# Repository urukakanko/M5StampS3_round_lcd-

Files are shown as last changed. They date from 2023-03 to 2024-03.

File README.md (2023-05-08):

# M5StampS3ラウンド液晶モジュール

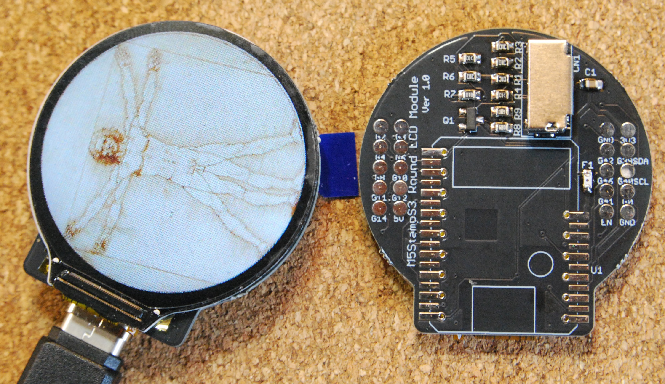
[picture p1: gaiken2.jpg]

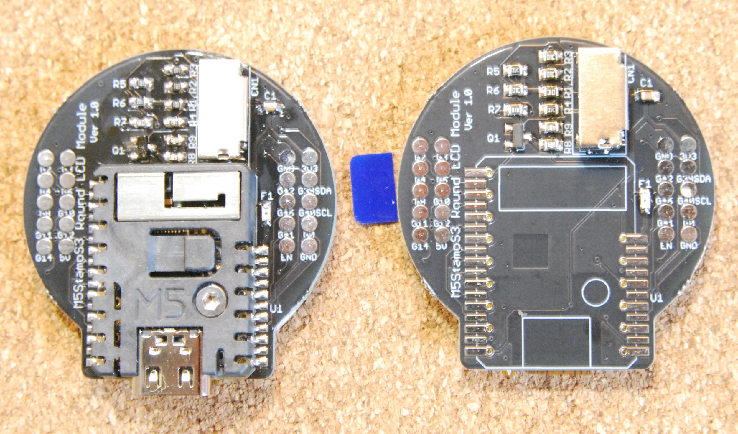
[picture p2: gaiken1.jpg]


写真左：M5StampS3実装済　　　　写真右：M5StampS3未実装

M5StampS3を使用して1.28インチ240ｘ240ドットの円形液晶を駆動する基板モジュールです。

円形液晶の裏にM5StampS3を配置することで、とても小さくスリムな形状になりました。

円形液晶にはGC9A01というコントローラーが使用されていますが、対応したグラフィックライブラリが数種類公開されています。

本モジュールは「グラフィックライブラリの使い方を理解して液晶モジュールを駆動出来る人」をターゲットにしております。

# 2023年5月5日までにM5StampS3実装品を購入された方へのお詫び

裏面のMacAddressがプリントされたラベルと実際のMacAddressが異なっている可能性があります。

MacAddress情報が必要な場合は以下サンプルソースで画面表示する様にしましたのでこちらで確認をお願いします。

大変ご迷惑をお掛けしてしまい申し訳ございません。

https://github.com/urukakanko/M5StampS3_round_lcd-/tree/main/M5stampS3_ClockSample

# <span style="color: red;">注意！！（必ずお読み下さい）</span>

本品は基本的な電子回路の仕組みを理解した方を対象とした、電子部品がむき出しの半完成キットです。
電子部品は電源電圧や極性を間違えたり、部品を破損させたり部品端子をショートさせた場合、発熱・発煙・発火に至る場合もあります。
間違った使い方をすると危険である事を理解された方のみご使用ください。
趣味の電子工作向けに製作しておりますので、製品への組込みや日常生活へ組込んでのご使用はお控え下さい。

# 形状および回路図

以下に外形イメージを示します

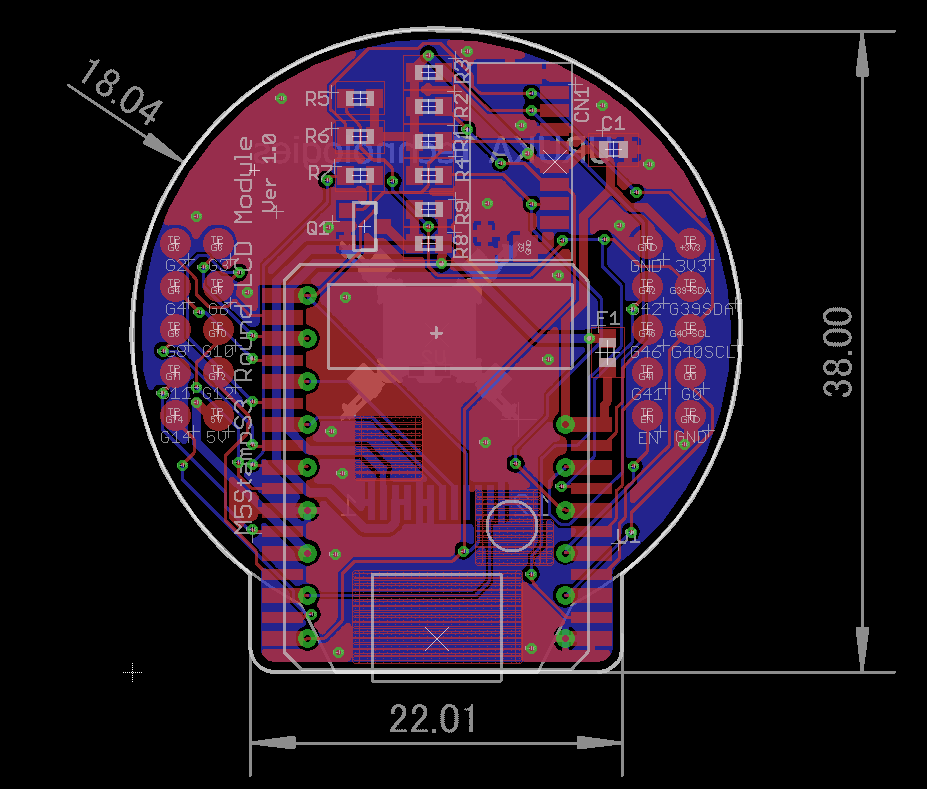
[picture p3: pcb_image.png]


以下に回路図を示します　現在最新は基板Ver1.0です

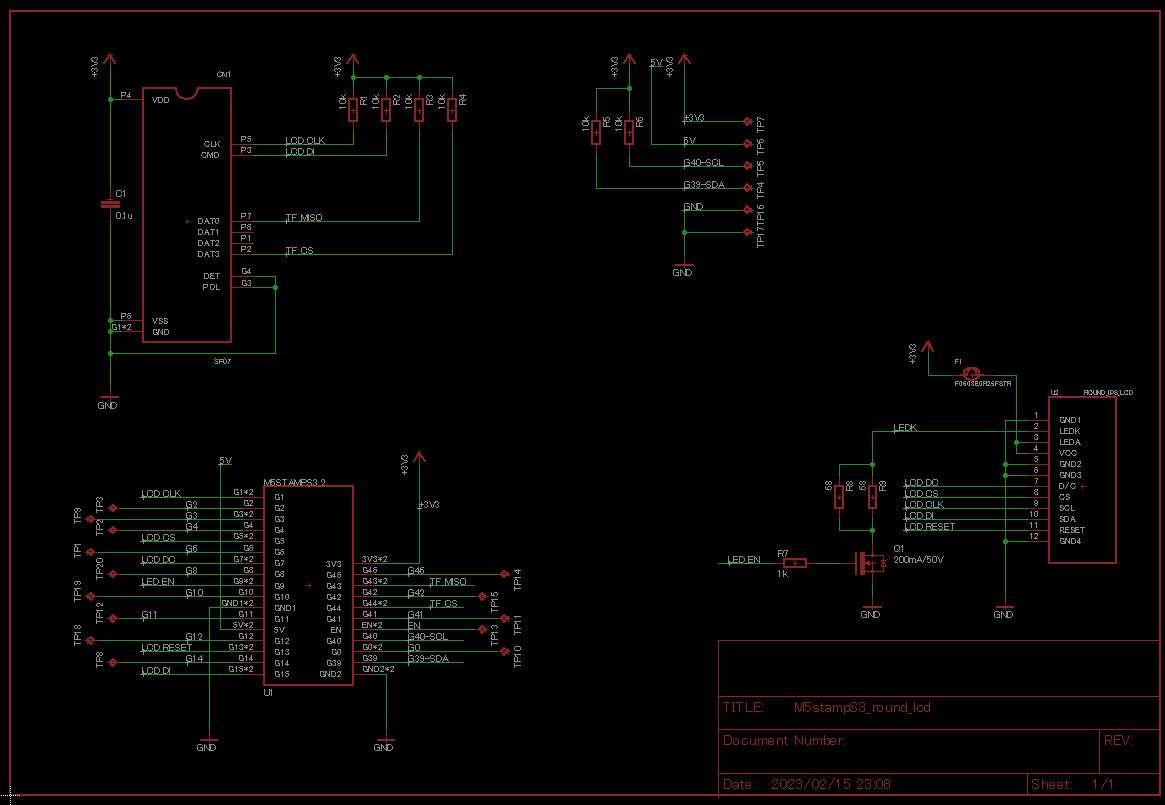
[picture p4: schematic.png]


試作版のVer0.1の図面は以下に保存しています

https://github.com/urukakanko/M5StampS3_round_lcd-/tree/main/ver0.1

# ピンアサイン

M5Stamp とLCDの制御信号とのピン接続は以下となります。

- SCLK:G1

- DATA-IN:G15

- DC:G7

- CS:G5

- RST:G13

- バックライト:G9　バックライトLEDのPIN設定は必ず行ってください。ハイインピーダンスとなった場合バックライトが不安定になります。

TFカードスロットのPIN接続は以下となります。（SCLKおよびMOSIは液晶と共通です）

- TF-MISO:G43
- TF-CS:44

また、以下の未使用PINはパットで引き出せるようにしました。I2C接続を想定しG39とG40にはプルアップをしています。

- G2,G3,G4,G6,G8,G10,G11,G12,G14,G39,G0,G40,EN,G41,G42,G46

注意：リード線をハンダ付けするパットとして使用します　コネクタやピンヘッダは挿せません。

# 使用するツールやライブラリ

M5StampS3の情報については、以下サイトを参考下さい。

https://docs.m5stack.com/en/core/StampS3

グラフィックライブラリについてはlovyanさまのLovyanGFXにて動作確認をしています。

https://github.com/lovyan03/LovyanGFX

他、GC9A01に対応したライブラリが使用可能と考えています。

# サンプルプログラム

LovyanGFXのClockSampleです

https://github.com/urukakanko/M5StampS3_round_lcd-/tree/main/M5stampS3_ClockSample

# LCD表示動画

BMPデータを液晶に表示しています

[https://youtu.be/gN_2BcIaoQU](https://youtu.be/WFxbUNVwUNw)

未実装版のチェックをしている動画です

https://youtu.be/jMZeYKtBkwM

# そーたメイ氏の「つくるっち」に対応して頂きました

以下はアニメーションデモです

https://sohta02.sakura.ne.jp/tukurutch/#000000531

# 使用例

準備中

# スイッチサイエンスマーケットプレイスで販売しています

M5StampS3実装品

https://www.switch-science.com/products/8971

M5StampS3未実装品

https://www.switch-science.com/products/8851

# 製作者

ウルカテクノロジー
Hiroyuki Sunagawa

https://www.facebook.com/URUKA-Technologies-105478404379918

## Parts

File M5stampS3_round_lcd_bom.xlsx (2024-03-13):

Column1 | Column2 | Column3 | Column4 | Column5
Part | Value | Device | Package | Description
C1 | 0.1u | C-EUC0603 | C0603 | CAPACITOR, European symbol
CN1 | 8pin | HYC80-TF08-375 |  | mini TF card socket
F1 | 250mA | FUSE0603 | C0603 | Can be replaced with 0 ohm resistor
Q1 | BSS138 | MOSFET-NCHANNELBSS138 | SOT23-3
R1 | 10k | R-EU_R0603 | R0603 | RESISTOR
R2 | 10k | R-EU_R0603 | R0603 | RESISTOR
R3 | 10k | R-EU_R0603 | R0603 | RESISTOR
R4 | 10k | R-EU_R0603 | R0603 | RESISTOR
R5 | 10k | R-EU_R0603 | R0603 | RESISTOR
R6 | 10k | R-EU_R0603 | R0603 | RESISTOR
R7 | 1k | R-EU_R0603 | R0603 | RESISTOR
R8 | 68 | R-EU_R0603 | R0603 | RESISTOR
R9 | 68 | R-EU_R0603 | R0603 | RESISTOR
U1 | M5STAMPS3 | M5STAMPS3 | M5STAMPS3
U2 | ROUND_IPS_LCD | ROUND_IPS_LCD | ROUND_IPS_LCD

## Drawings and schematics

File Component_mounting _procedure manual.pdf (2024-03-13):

# Component mounting procedure manual

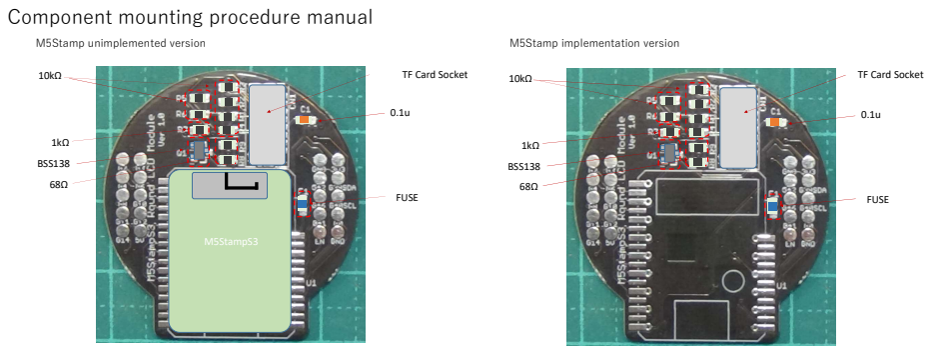
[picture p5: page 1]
M5Stamp unimplemented version; M5Stamp implementation version; M5Stamp実装品; M5StampS3; FUSE; BSS138; 1kΩ BSS138; TF Card Socket

# Round LCD implementation

Front side | Back side

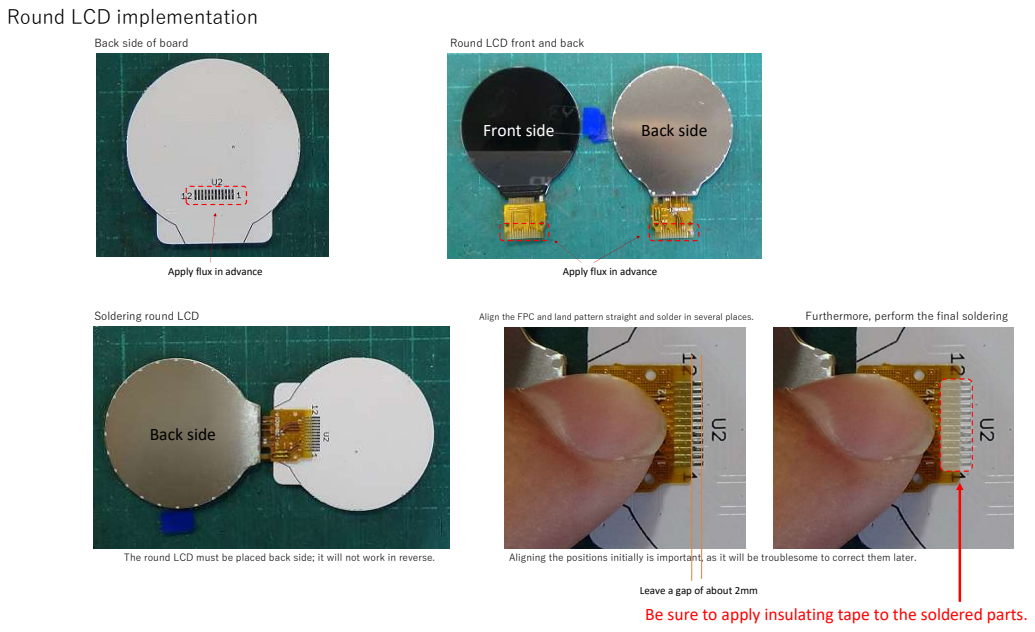
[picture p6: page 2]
Back side of board; Round LCD front and back; Soldering round LCD; Align the FPC and land pattern straight and solder in several places.; Furthermore, perform the final soldering; The round LCD must be placed back side; it will not work in reverse.; Aligning the positions initially is important, as it will be troublesome to correct them later.; Apply flux in advance; Back side

Leave a gap of about 2mm
Be sure to apply insulating tape to the soldered parts.

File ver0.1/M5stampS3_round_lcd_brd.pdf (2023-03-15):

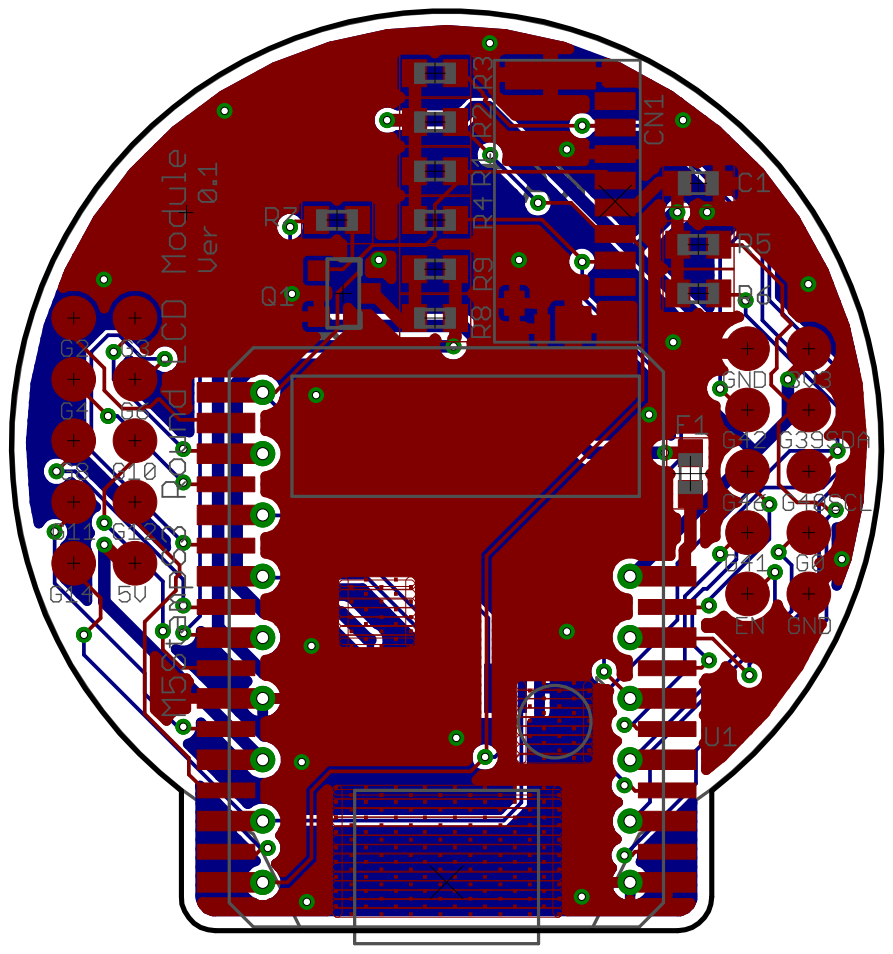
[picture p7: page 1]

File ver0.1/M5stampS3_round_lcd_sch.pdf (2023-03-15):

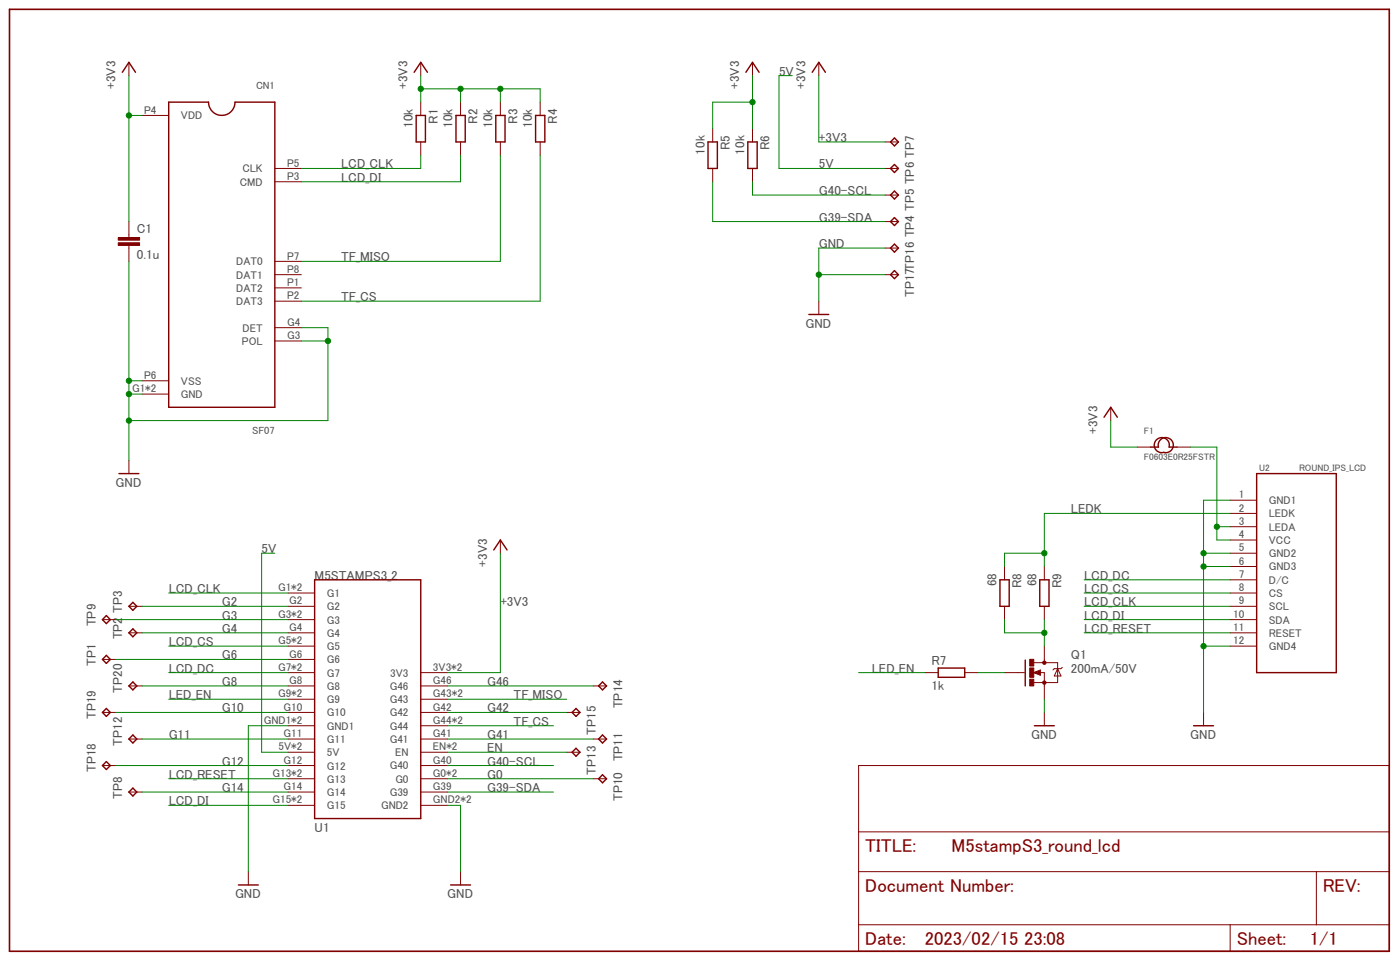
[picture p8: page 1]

Document Number: | REV:

Date: 2023/02/15 23:08 | Sheet: 1/1

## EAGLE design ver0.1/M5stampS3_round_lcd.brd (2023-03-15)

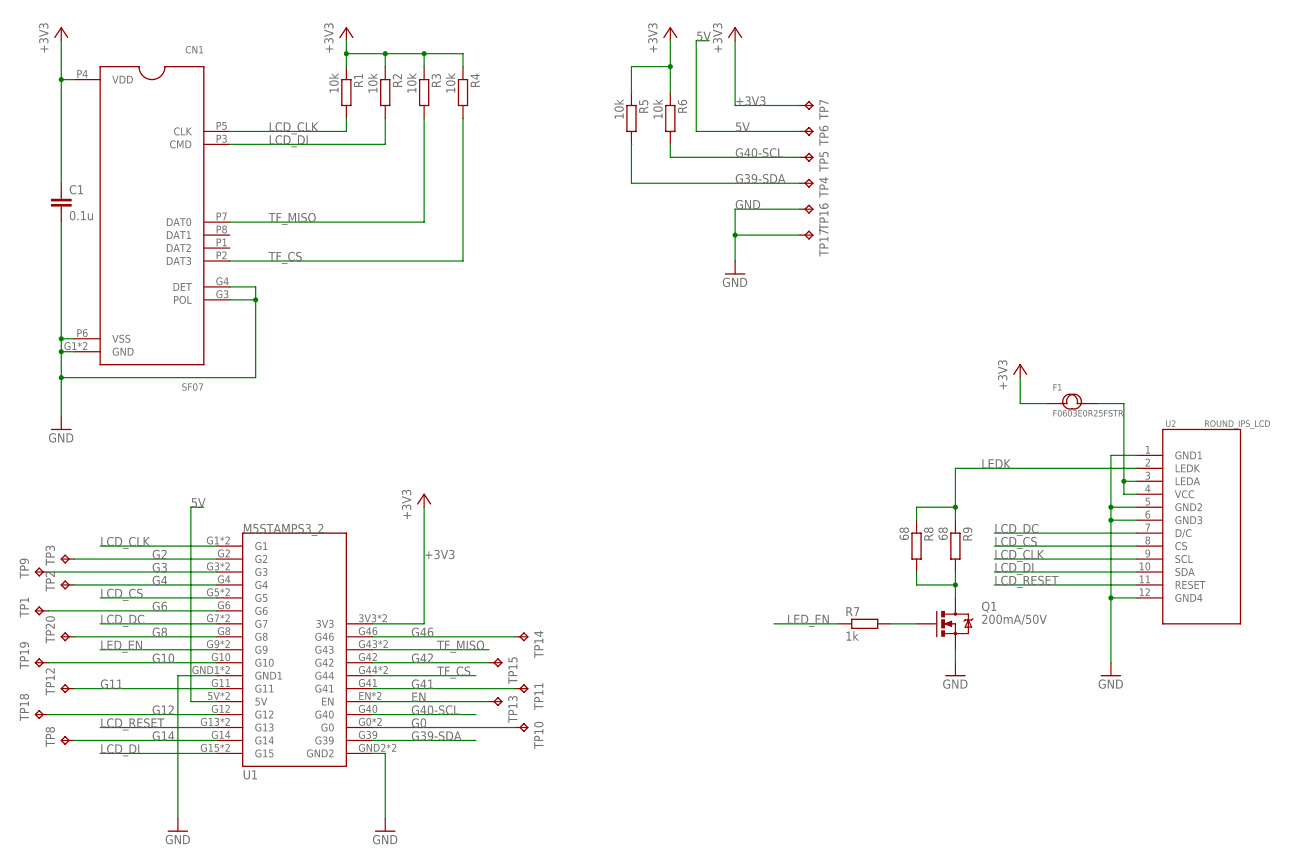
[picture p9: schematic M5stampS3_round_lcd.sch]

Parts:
C1: 0.1u; C0603
CN1: SF07; POS-8
F1: F0603E0R25FSTR; C0603
Q1: 200mA/50V; SOT23-3
R1, R2, R3, R4, R5, R6: 10k; R0603
R7: 1k; R0603
R8, R9: 68; R0603
TP1, TP2, TP3, TP4, TP5, TP6, TP7, TP8, TP9, TP10, TP11, TP12, TP13, TP14, TP15, TP16, TP17, TP18, TP19, TP20: TPTP18R; TP18R
U1: M5STAMPS3_2
U2: ROUND_IPS_LCD

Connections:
5V: TP6.TP, U1.5V, U1.5V_ (5V)
+3V3: C1.1, CN1.P4 (VDD), F1.1, R1.1, R2.1, R3.1, R4.1, R5.1, R6.1, TP7.TP, U1.3V3, U1.3V3_ (3V3)
EN: TP13.TP, U1.EN, U1.EN_ (EN)
G0: TP10.TP, U1.G0, U1.G0_ (G0)
G2: TP3.TP, U1.G2
G3: TP9.TP, U1.G3, U1.G3_ (G3)
G4: TP2.TP, U1.G4
G6: TP1.TP, U1.G6
G8: TP20.TP, U1.G8
G10: TP19.TP, U1.G10
G11: TP12.TP, U1.G11
G12: TP18.TP, U1.G12
G14: TP8.TP, U1.G14
G39-SDA: R5.2, TP4.TP, U1.G39
G40-SCL: R6.2, TP5.TP, U1.G40
G41: TP11.TP, U1.G41
G42: TP15.TP, U1.G42
G46: TP14.TP, U1.G46
GND: C1.2, CN1.G1 (GND), CN1.G2 (GND), CN1.G3 (POL), CN1.G4 (DET), CN1.P6 (VSS), Q1.2 (S), TP16.TP, TP17.TP, U1.GND1, U1.GND1_ (GND1), U1.GND2, U1.GND2_ (GND2), U2.1 (GND1), U2.5 (GND2), U2.6 (GND3), U2.12 (GND4)
LCD_CLK: CN1.P5 (CLK), R1.2, U1.G1, U1.G1_ (G1), U2.9 (SCL)
LCD_CS: U1.G5, U1.G5_ (G5), U2.8 (CS)
LCD_DC: U1.G7, U1.G7_ (G7), U2.7 (D/C)
LCD_DI: CN1.P3 (CMD), R2.2, U1.G15, U1.G15_ (G15), U2.10 (SDA)
LCD_RESET: U1.G13, U1.G13_ (G13), U2.11 (RESET)
LEDK: R8.1, R9.1, U2.2 (LEDK)
LED_EN: R7.1, U1.G9, U1.G9_ (G9)
unnamed: Q1.3 (D), R8.2, R9.2
unnamed: Q1.1 (G), R7.2
unnamed: F1.2, U2.3 (LEDA), U2.4 (VCC)
TF_CS: CN1.P2 (DAT3), R4.2, U1.G44, U1.G44_ (G44)
TF_MISO: CN1.P7 (DAT0), R3.2, U1.G43, U1.G43_ (G43)

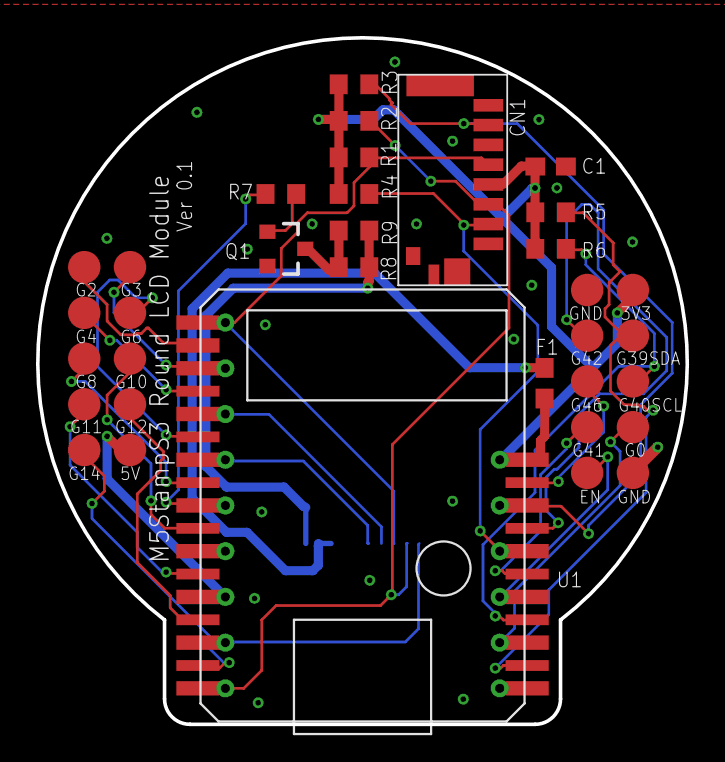
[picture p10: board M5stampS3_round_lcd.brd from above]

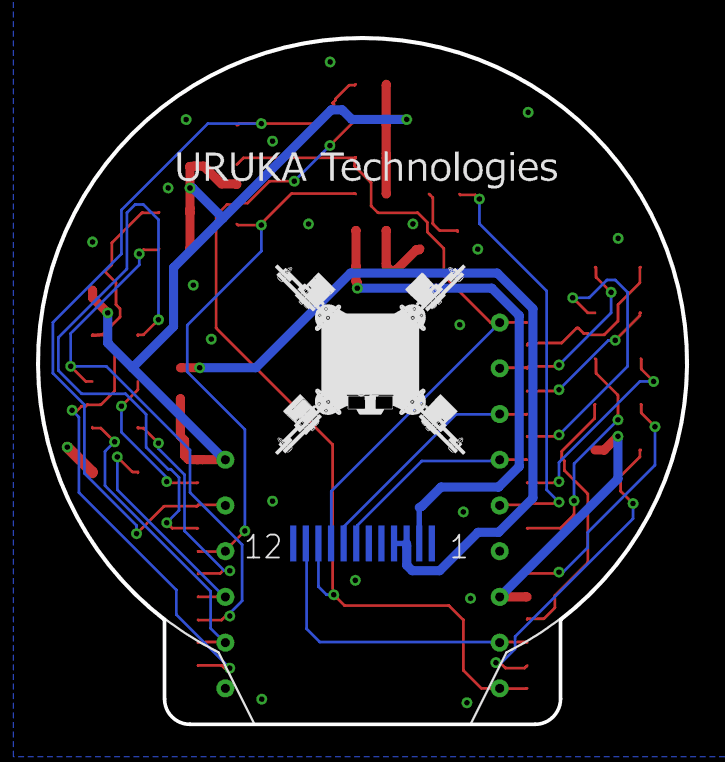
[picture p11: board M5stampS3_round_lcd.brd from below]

Board: 2 copper layers, 36.1 x 38.1 mm, 37 parts (2 on the bottom side), 31 nets.

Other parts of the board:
U$1: QC02
U$2: URUKA

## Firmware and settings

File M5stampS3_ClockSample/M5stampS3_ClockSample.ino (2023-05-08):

#define LGFX_USE_V1
#include <LovyanGFX.hpp>

class LGFX_ESP32_SPI_GC9A01 : public lgfx::LGFX_Device
{
lgfx::Panel_GC9A01      _panel_instance;
lgfx::Bus_SPI       _bus_instance;   // SPIバスのインスタンス
lgfx::Light_PWM     _light_instance;
public:
  LGFX_ESP32_SPI_GC9A01(void)
  {
    { // バス制御の設定を行います。
      auto cfg = _bus_instance.config();    // バス設定用の構造体を取得します。

// SPIバスの設定
      cfg.spi_host = SPI2_HOST;     // 使用するSPIを選択  ESP32-S2,C3 : SPI2_HOST or SPI3_HOST / ESP32 : VSPI_HOST or HSPI_HOST
      // ※ ESP-IDFバージョンアップに伴い、VSPI_HOST , HSPI_HOSTの記述は非推奨になるため、エラーが出る場合は代わりにSPI2_HOST , SPI3_HOSTを使用してください。
      cfg.spi_mode = 0;             // SPI通信モードを設定 (0 ~ 3)
      cfg.freq_write = 40000000;    // 送信時のSPIクロック (最大80MHz, 80MHzを整数で割った値に丸められます)
      cfg.freq_read  = 16000000;    // 受信時のSPIクロック
      cfg.spi_3wire  = true;        // 受信をMOSIピンで行う場合はtrueを設定
      cfg.use_lock   = true;        // トランザクションロックを使用する場合はtrueを設定
      cfg.dma_channel = SPI_DMA_CH_AUTO; // 使用するDMAチャンネルを設定 (0=DMA不使用 / 1=1ch / 2=ch / SPI_DMA_CH_AUTO=自動設定)
      // ※ ESP-IDFバージョンアップに伴い、DMAチャンネルはSPI_DMA_CH_AUTO(自動設定)が推奨になりました。1ch,2chの指定は非推奨になります。
      cfg.pin_sclk = 1;            // SPIのSCLKピン番号を設定
      cfg.pin_mosi = 15;            // SPIのMOSIピン番号を設定
      cfg.pin_miso = 43;            // SPIのMISOピン番号を設定 (-1 = disable)
      cfg.pin_dc   = 7;            // SPIのD/Cピン番号を設定  (-1 = disable)
     // SDカードと共通のSPIバスを使う場合、MISOは省略せず必ず設定してください。
      _bus_instance.config(cfg);    // 設定値をバスに反映します。
      _panel_instance.setBus(&_bus_instance);      // バスをパネルにセットします。
    }

    { // 表示パネル制御の設定を行います。
      auto cfg = _panel_instance.config();    // 表示パネル設定用の構造体を取得します。
      cfg.pin_cs           =    5;  // CSが接続されているピン番号   (-1 = disable)
      cfg.pin_rst          =    13;  // RSTが接続されているピン番号  (-1 = disable)
      cfg.pin_busy         =    -1;  // BUSYが接続されているピン番号 (-1 = disable)
      // ※ 以下の設定値はパネル毎に一般的な初期値が設定されていますので、不明な項目はコメントアウトして試してみてください。
      cfg.memory_width     =   240;  // ドライバICがサポートしている最大の幅
      cfg.memory_height    =   240;  // ドライバICがサポートしている最大の高さ
      cfg.panel_width      =   240;  // 実際に表示可能な幅
      cfg.panel_height     =   240;  // 実際に表示可能な高さ
      cfg.offset_x         =     0;  // パネルのX方向オフセット量
      cfg.offset_y         =     0;  // パネルのY方向オフセット量
      cfg.offset_rotation  =     0;  // 回転方向の値のオフセット 0~7 (4~7は上下反転)
      cfg.dummy_read_pixel =     8;  // ピクセル読出し前のダミーリードのビット数
      cfg.dummy_read_bits  =     1;  // ピクセル以外のデータ読出し前のダミーリードのビット数
      cfg.readable         =  true;  // データ読出しが可能な場合 trueに設定
      cfg.invert           =  true;  // パネルの明暗が反転してしまう場合 trueに設定
      cfg.rgb_order        = false;  // パネルの赤と青が入れ替わってしまう場合 trueに設定
      cfg.dlen_16bit       = false;  // データ長を16bit単位で送信するパネルの場合 trueに設定
      cfg.bus_shared       =  true;  // SDカードとバスを共有している場合 trueに設定(drawJpgFile等でバス制御を行います)

      _panel_instance.config(cfg);
    }
    { // バックライト制御の設定を行います。（必要なければ削除）
      auto cfg = _light_instance.config();    // バックライト設定用の構造体を取得します。

      cfg.pin_bl = 9;              // バックライトが接続されているピン番号
      cfg.invert = false;           // バックライトの輝度を反転させる場合 true
      cfg.freq   = 44100;           // バックライトのPWM周波数
      cfg.pwm_channel = 3;          // 使用するPWMのチャンネル番号

      _light_instance.config(cfg);
      _panel_instance.setLight(&_light_instance);  // バックライトをパネルにセットします。
    }
    setPanel(&_panel_instance); // 使用するパネルをセットします。
  }
};

LGFX_ESP32_SPI_GC9A01 lcd;
//static LGFX lcd;
static LGFX_Sprite canvas(&lcd);       // オフスクリーン描画用バッファ
static LGFX_Sprite clockbase(&canvas); // 時計の文字盤パーツ
static LGFX_Sprite needle1(&canvas);   // 長針・短針パーツ
static LGFX_Sprite shadow1(&canvas);   // 長針・短針の影パーツ
static LGFX_Sprite needle2(&canvas);   // 秒針パーツ
static LGFX_Sprite shadow2(&canvas);   // 秒針の影パーツ

static constexpr uint64_t oneday = 86400000; // 1日 = 1000msec x 60sec x 60min x 24hour = 86400000
static uint64_t count = rand() % oneday;    // 現在時刻 (ミリ秒カウンタ)
static int32_t width = 239;             // 時計の縦横画像サイズ
static int32_t halfwidth = width >> 1;  // 時計盤の中心座標
static auto transpalette = 0;           // 透過色パレット番号
static float zoom;                      // 表示倍率

#ifdef min
#undef min
#endif

void setup(void)
{
  lcd.init();

  lcd.clear(TFT_BLACK);
  uint8_t Macaddress[6];
  esp_read_mac(Macaddress, ESP_MAC_WIFI_STA);
  lcd.setFont(&fonts::Font4); 
  lcd.setCursor(10, 110);
  lcd.printf("%02X:%02X:%02X:%02X:%02X:%02X", Macaddress[0], Macaddress[1], Macaddress[2], Macaddress[3], Macaddress[4], Macaddress[5]);

  delay(4000);

  zoom = (float)(std::min(lcd.width(), lcd.height())) / width; // 表示が画面にフィットするよう倍率を調整

  lcd.setPivot(lcd.width() >> 1, lcd.height() >> 1); // 時計描画時の中心を画面中心に合わせる

  canvas.setColorDepth(lgfx::palette_4bit);  // 各部品を４ビットパレットモードで準備する
  clockbase.setColorDepth(lgfx::palette_4bit);
  needle1.setColorDepth(lgfx::palette_4bit);
  shadow1.setColorDepth(lgfx::palette_4bit);
  needle2.setColorDepth(lgfx::palette_4bit);
  shadow2.setColorDepth(lgfx::palette_4bit);
// パレットの初期色はグレースケールのグラデーションとなっており、
// 0番が黒(0,0,0)、15番が白(255,255,255)
// 1番～14番は黒から白へ段階的に明るさが変化している
//
// パレットを使う場合、描画関数は色の代わりに0～15のパレット番号を指定する

  canvas.createSprite(width, width); // メモリ確保
  clockbase.createSprite(width, width);
  needle1.createSprite(9, 119);
  shadow1.createSprite(9, 119);
  needle2.createSprite(3, 119);
  shadow2.createSprite(3, 119);

  canvas.fillScreen(transpalette); // 透過色で背景を塗り潰す (create直後は0埋めされているので省略可能)
  clockbase.fillScreen(transpalette);
  needle1.fillScreen(transpalette);
  shadow1.fillScreen(transpalette);

  clockbase.setTextFont(4);           // フォント種類を変更(時計盤の文字用)
  clockbase.setTextDatum(lgfx::middle_center);
  clockbase.fillCircle(halfwidth, halfwidth, halfwidth    ,  6); // 時計盤の背景の円を塗る
  clockbase.drawCircle(halfwidth, halfwidth, halfwidth - 1, 15);
  for (int i = 1; i <= 60; ++i) {
    float rad = i * 6 * - 0.0174532925;              // 時計盤外周の目盛り座標を求める
    float cosy = - cos(rad) * (halfwidth * 10 / 11);
    float sinx = - sin(rad) * (halfwidth * 10 / 11);
    bool flg = 0 == (i % 5);      // ５目盛り毎フラグ
    clockbase.fillCircle(halfwidth + sinx + 1, halfwidth + cosy + 1, flg * 3 + 1,  4); // 目盛りを描画
    clockbase.fillCircle(halfwidth + sinx    , halfwidth + cosy    , flg * 3 + 1, 12);
    if (flg) {                    // 文字描画
      cosy = - cos(rad) * (halfwidth * 10 / 13);
      sinx = - sin(rad) * (halfwidth * 10 / 13);
      clockbase.setTextColor(1);
      clockbase.drawNumber(i/5, halfwidth + sinx + 1, halfwidth + cosy + 4);
      clockbase.setTextColor(15);
      clockbase.drawNumber(i/5, halfwidth + sinx    , halfwidth + cosy + 3);
    }
  }
  clockbase.setTextFont(7);

  needle1.setPivot(4, 100);  // 針パーツの回転中心座標を設定する
  shadow1.setPivot(4, 100);
  needle2.setPivot(1, 100);
  shadow2.setPivot(1, 100);

  for (int i = 6; i >= 0; --i) {  // 針パーツの画像を作成する
    needle1.fillTriangle(4, - 16 - (i<<1), 8, needle1.height() - (i<<1), 0, needle1.height() - (i<<1), 15 - i);
    shadow1.fillTriangle(4, - 16 - (i<<1), 8, shadow1.height() - (i<<1), 0, shadow1.height() - (i<<1),  1 + i);
  }
  for (int i = 0; i < 7; ++i) {
    needle1.fillTriangle(4, 16 + (i<<1), 8, needle1.height() + 32 + (i<<1), 0, needle1.height() + 32 + (i<<1), 15 - i);
    shadow1.fillTriangle(4, 16 + (i<<1), 8, shadow1.height() + 32 + (i<<1), 0, shadow1.height() + 32 + (i<<1),  1 + i);
  }
  needle1.fillTriangle(4, 32, 8, needle1.height() + 64, 0, needle1.height() + 64, 0);
  shadow1.fillTriangle(4, 32, 8, shadow1.height() + 64, 0, shadow1.height() + 64, 0);
  needle1.fillRect(0, 117, 9, 2, 15);
  shadow1.fillRect(0, 117, 9, 2,  1);
  needle1.drawFastHLine(1, 117, 7, 12);
  shadow1.drawFastHLine(1, 117, 7,  4);

  needle1.fillCircle(4, 100, 4, 15);
  shadow1.fillCircle(4, 100, 4,  1);
  needle1.drawCircle(4, 100, 4, 14);

  needle2.fillScreen(9);
  shadow2.fillScreen(3);
  needle2.drawFastVLine(1, 0, 119, 8);
  shadow2.drawFastVLine(1, 0, 119, 1);
  needle2.fillRect(0, 99, 3, 3, 8);

  lcd.startWrite();
  lcd.setBrightness(128);
//  shadow1.pushSprite(&lcd,  0, 0); // デバッグ用、パーツを直接LCDに描画する
//  needle1.pushSprite(&lcd, 10, 0);
//  shadow2.pushSprite(&lcd, 20, 0);
//  needle2.pushSprite(&lcd, 25, 0);
}

void update7Seg(int32_t hour, int32_t min)
{ // 時計盤のデジタル表示部の描画
  int x = clockbase.getPivotX() - 69;
  int y = clockbase.getPivotY();
  clockbase.setCursor(x, y);
  clockbase.setTextColor(5);  // 消去色で 88:88 を描画する
  clockbase.print("88:88");
  clockbase.setCursor(x, y);
  clockbase.setTextColor(12); // 表示色で時:分を描画する
  clockbase.printf("%02d:%02d", hour, min);
}

void drawDot(int pos, int palette)
{
  bool flg = 0 == (pos % 5);      // ５目盛り毎フラグ
  float rad = pos * 6 * - 0.0174532925;              // 時計盤外周の目盛り座標を求める
  float cosy = - cos(rad) * (halfwidth * 10 / 11);
  float sinx = - sin(rad) * (halfwidth * 10 / 11);
  canvas.fillCircle(halfwidth + sinx, halfwidth + cosy, flg * 3 + 1, palette);
}

void drawClock(uint64_t time)
{ // 時計の描画
  static int32_t p_min = -1;
  int32_t sec = time / 1000;
  int32_t min = sec / 60;
  if (p_min != min) { // 分の値が変化していれば時計盤のデジタル表示部分を更新
    p_min = min;
    update7Seg(min / 60, min % 60);
  }
  clockbase.pushSprite(0, 0);  // 描画用バッファに時計盤の画像を上書き

  drawDot(sec % 60, 14);
  drawDot(min % 60, 15);
  drawDot(((min/60)*5)%60, 15);

  float fhour = (float)time / 120000;  // 短針の角度
  float fmin  = (float)time /  10000;  // 長針の角度
  float fsec  = (float)time*6 / 1000;  // 秒針の角度
  int px = canvas.getPivotX();
  int py = canvas.getPivotY();
  shadow1.pushRotateZoom(px+2, py+2, fhour, 1.0, 0.7, transpalette); // 針の影を右下方向にずらして描画する
  shadow1.pushRotateZoom(px+3, py+3, fmin , 1.0, 1.0, transpalette);
  shadow2.pushRotateZoom(px+4, py+4, fsec , 1.0, 1.0, transpalette);
  needle1.pushRotateZoom(            fhour, 1.0, 0.7, transpalette); // 針を描画する
  needle1.pushRotateZoom(            fmin , 1.0, 1.0, transpalette);
  needle2.pushRotateZoom(            fsec , 1.0, 1.0, transpalette);

  canvas.pushRotateZoom(0, zoom, zoom, transpalette);    // 完了した時計盤をLCDに描画する
  lcd.display();
}

void loop(void)
{
  static uint32_t p_milli = 0;
  uint32_t milli = lgfx::millis() % 1000;
  if (p_milli < milli) count +=        (milli - p_milli);
  else                 count += 1000 + (milli - p_milli);
  p_milli = milli;

  int32_t tmp = (count % 1000) >> 3;
  canvas.setPaletteColor(8, 255 - (tmp>>1), 255 - (tmp>>1), 200 - tmp); // 秒針の描画色を変化させる
//count += 60000;
  if ( count > oneday ) { count -= oneday; }
  drawClock(count);
}

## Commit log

2023-05-08 MacAddress表示を追加
2024-03-10 Gerber file

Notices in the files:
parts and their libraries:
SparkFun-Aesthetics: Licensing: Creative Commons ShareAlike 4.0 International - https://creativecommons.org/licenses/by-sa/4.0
